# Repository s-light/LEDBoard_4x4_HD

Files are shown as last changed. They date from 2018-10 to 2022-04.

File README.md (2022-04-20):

<!--lint disable list-item-indent-->
<!--lint disable list-item-bullet-indent-->

# LEDBoard_4x4_HD
PCB originally designed for [magic_amulet](https://github.com/s-light/magic_amulet),  
but now used in [magic_crystal](https://github.com/s-light/magic_crystal)

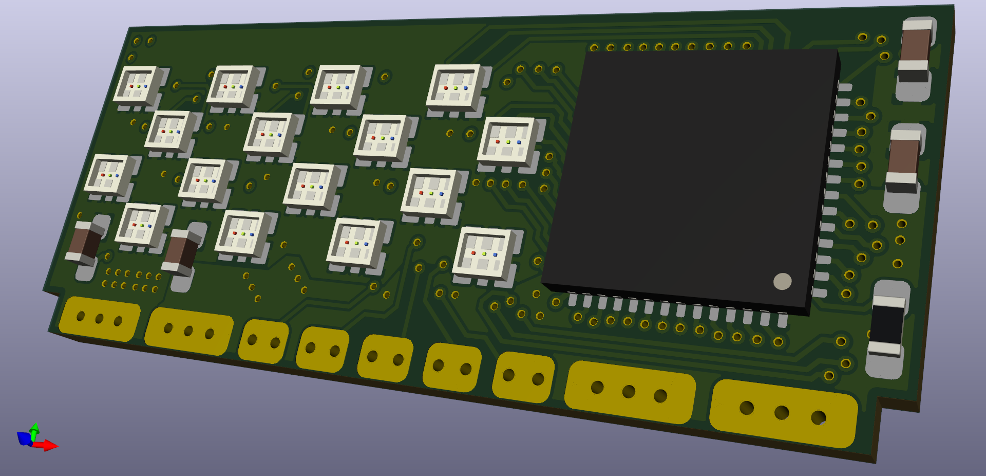
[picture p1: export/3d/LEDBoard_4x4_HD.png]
LEDBoard_4x4_HD CAD

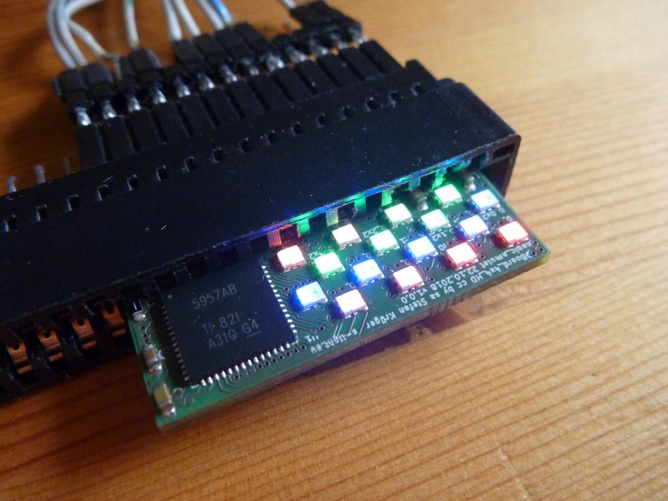
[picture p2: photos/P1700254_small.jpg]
LEDBoard_4x4_HD working

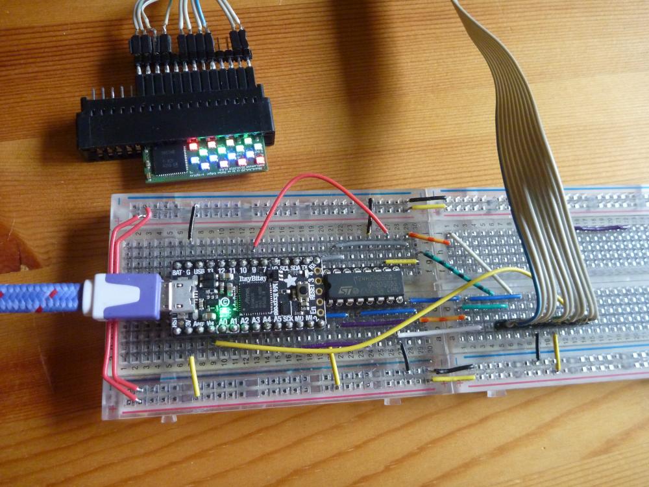
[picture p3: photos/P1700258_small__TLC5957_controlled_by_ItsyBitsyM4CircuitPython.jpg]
LEDBoard_4x4_HD controlled by ItsyBitsy M4 with CircuitPython


Overall Size:  
33mm x 14mm

### PCB
4layer board - uses 150mil traces and 100mil trace spacing  
shown pcb came from [aisler](https://aisler.net/s-light/magic_amulet/led-board-4x4-hd)

### parts
LED-Driver: [TLC5957](http://www.ti.com/lit/ds/symlink/tlc5957.pdf) (48ch CC 9-16Bit-PWM driver)  
more information in AppNote [Build a High-Density, High-Refresh Rate, Multiplexing Panel With the TLC5957](http://www.ti.com/lit/ug/slvuaf0/slvuaf0.pdf)

LED: [Rohm MSL0402RGBU](https://www.rohm.com/products/led/chip-leds-multi-color-type/msl0402rgbu-product) (1.8x1.6x0.5mm RGB)

### BOM
can be ordered with aisler parts-package  
or also with this [list at mouser](https://www.mouser.com/ProjectManager/ProjectDetail.aspx?AccessID=e53c13ed09)  
or with plain part numbers:
```
Qty.    Mfr. No             Manufacturer            Description
16      MSL0402RGBU1        ROHM Semiconductor      Standard LEDs - SMD RGB 624/527/470nm 5V 400/550/180mcd 30mA
1       TLC5957RTQR         Texas Instruments       LED Lighting Drivers 48-channel, 16bit ES PWM LED driver
2       GRM188R61A226ME15D  Murata                  Multilayer Ceramic Capacitors MLCC - SMD/SMT 0603 22uF 10volts *Derate Voltage/Temp
2       GCM188R91E104KA37D  Murata                  Multilayer Ceramic Capacitors MLCC - SMD/SMT 0603 0.1uF 25volts X8R 10%
1       ERJ-PB3B7501V       Panasonic               Thick Film Resistors - SMD 0603 Anti-Surge Res. 0.1%, 7.5Kohm
```

### power & cooling
if you want to drive the leds with full power (up to 25mA/color)
you definitely need a heatsink.  
the pcb backside get to >= 60°C very fast without a heatsink!

also remember that one board needs up to 1.2A@5V = 6W

### constant current

```
RIREF(kΩ) = VIREF(V) / IOLCMax(mA)× Gain  | / Gain
RIREF(kΩ) / Gain = VIREF(V) / IOLCMax(mA)  | swap
Gain / RIREF(kΩ) = IOLCMax(mA) / VIREF(V)  | x VIREF(V)
Gain / RIREF(kΩ) x VIREF(V) = IOLCMax(mA)

Gain / 7.4kΩ x 1.2V = IOLCMax(mA)

```
|  Gain |  BC | IOLCMax |
| ----: | --: | ---: |
|  20.0 | 0x0 | 3.2mA |
|  39.5 | 0x1 | 6.4mA |
|  58.6 | 0x2 | 9.5mA |
|  80.9 | 0x3 |  13.1mA |
| 100.0 | 0x4 |  16.2mA |
| 113.3 | 0x5 |  18.4mA |
| 141.6 | 0x6 |  23.0mA |
| 154.5 | 0x7 |  25.0mA |

### Software
- [arduino library](https://github.com/s-light/slight_TLC5957)
- [CircuitPython library](https://github.com/s-light/slight_CircuitPython_TLC5957)

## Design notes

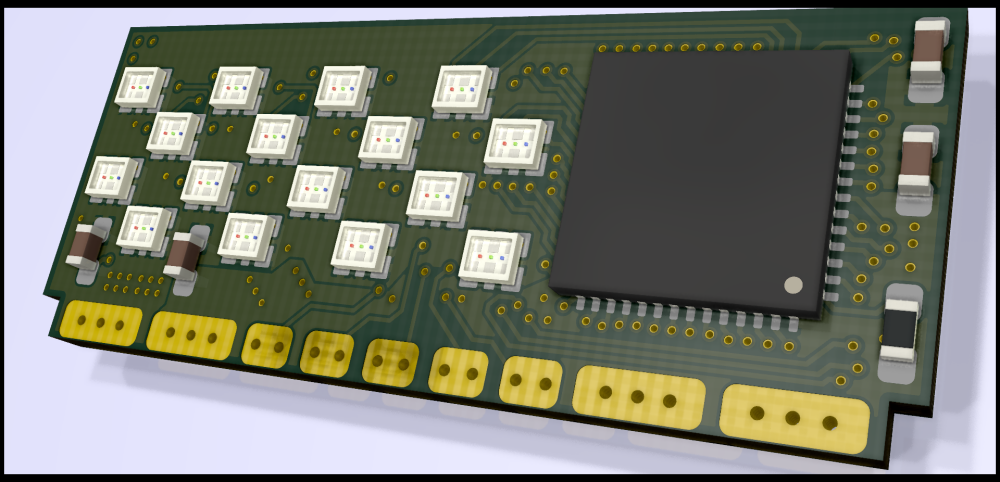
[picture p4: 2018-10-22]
export/3d/LEDBoard_4x4_HD_rendered_small.png

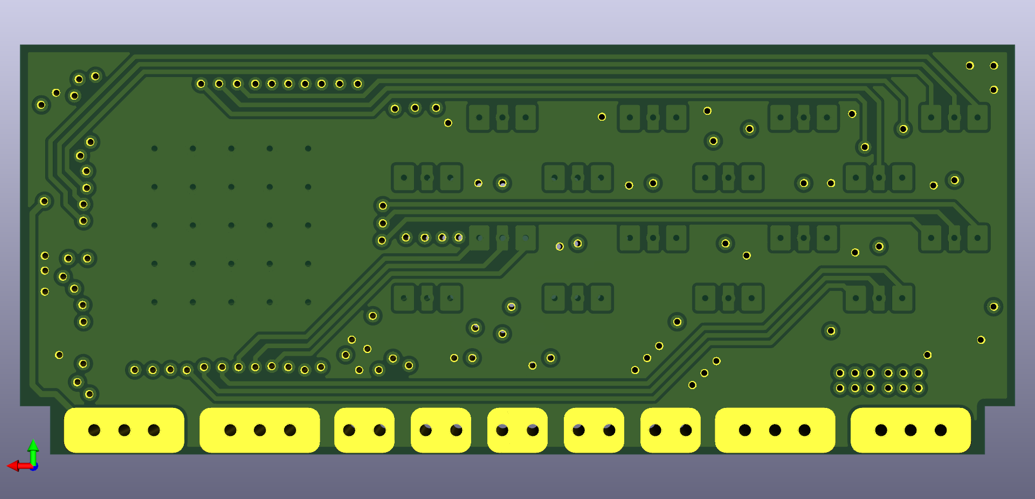
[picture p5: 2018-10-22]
export/3d/LEDBoard_4x4_HD_back.png

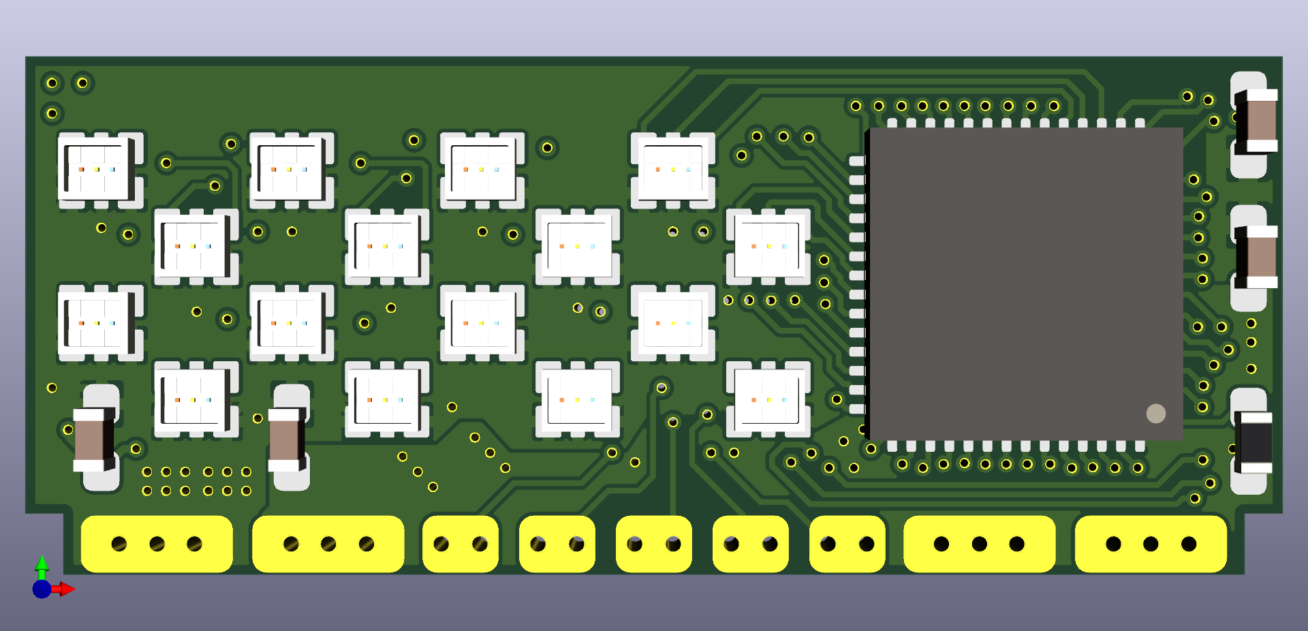
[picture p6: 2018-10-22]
export/3d/LEDBoard_4x4_HD_front.png

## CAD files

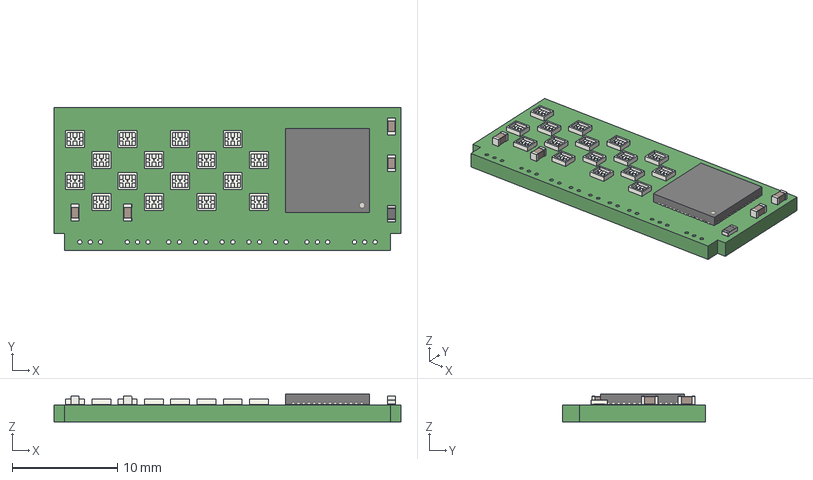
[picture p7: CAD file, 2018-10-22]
export/3d/LEDBoard_4x4_HD.step
33.0 x 13.6 x 2.65 mm

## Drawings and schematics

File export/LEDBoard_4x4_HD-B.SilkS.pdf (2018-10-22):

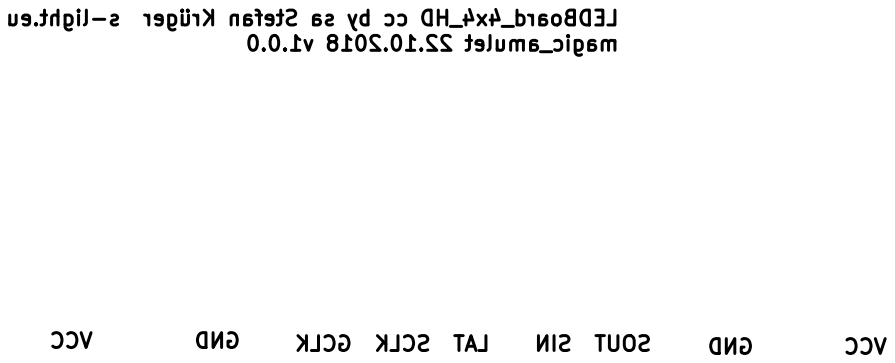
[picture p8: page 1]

LEDBoard_4x4_HD cc by sa Stefan Krüger s-light.eu magic_amulet 22.10.2018 v1.0.0

GND VCC SOUT SIN LAT SCLK GCLK VCC GND

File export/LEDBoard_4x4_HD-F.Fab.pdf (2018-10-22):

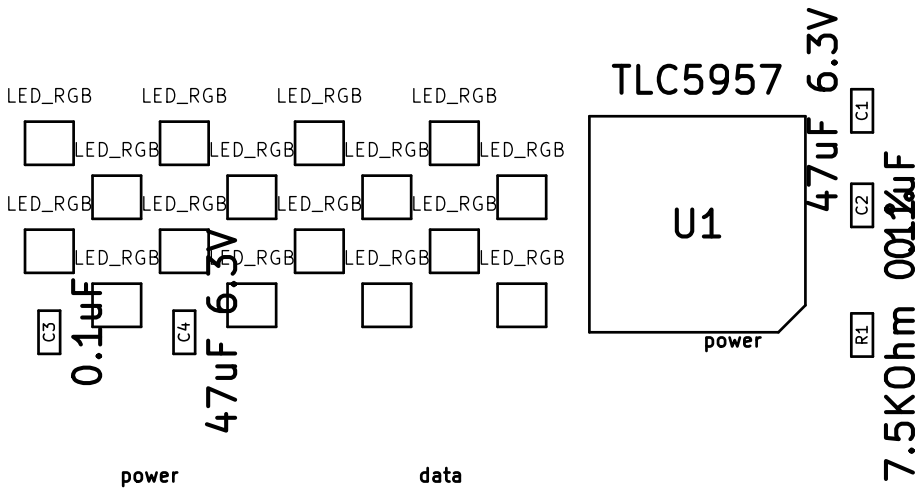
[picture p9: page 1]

LED_RGB | LED_RGB | LED_RGB

LED_RGB | | LED_RGB | LED_RGB

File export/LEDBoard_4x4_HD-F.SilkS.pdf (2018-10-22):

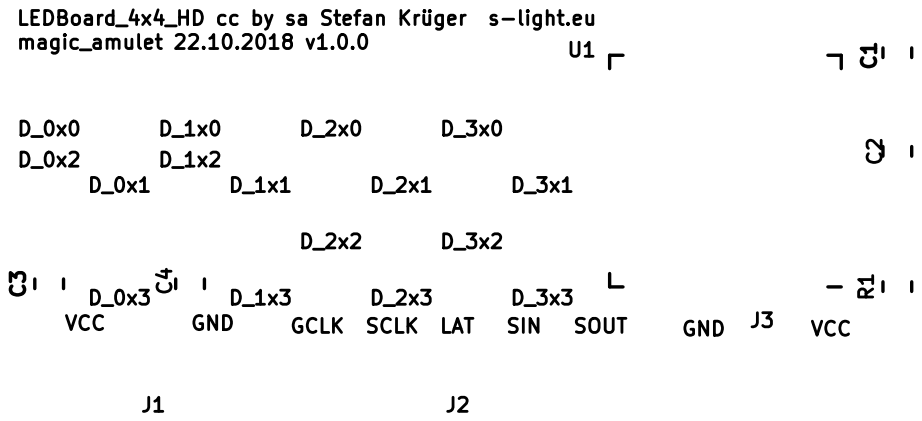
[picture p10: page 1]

LEDBoard_4x4_HD cc by sa Stefan Krüger s-light.eu magic_amulet 22.10.2018 v1.0.0

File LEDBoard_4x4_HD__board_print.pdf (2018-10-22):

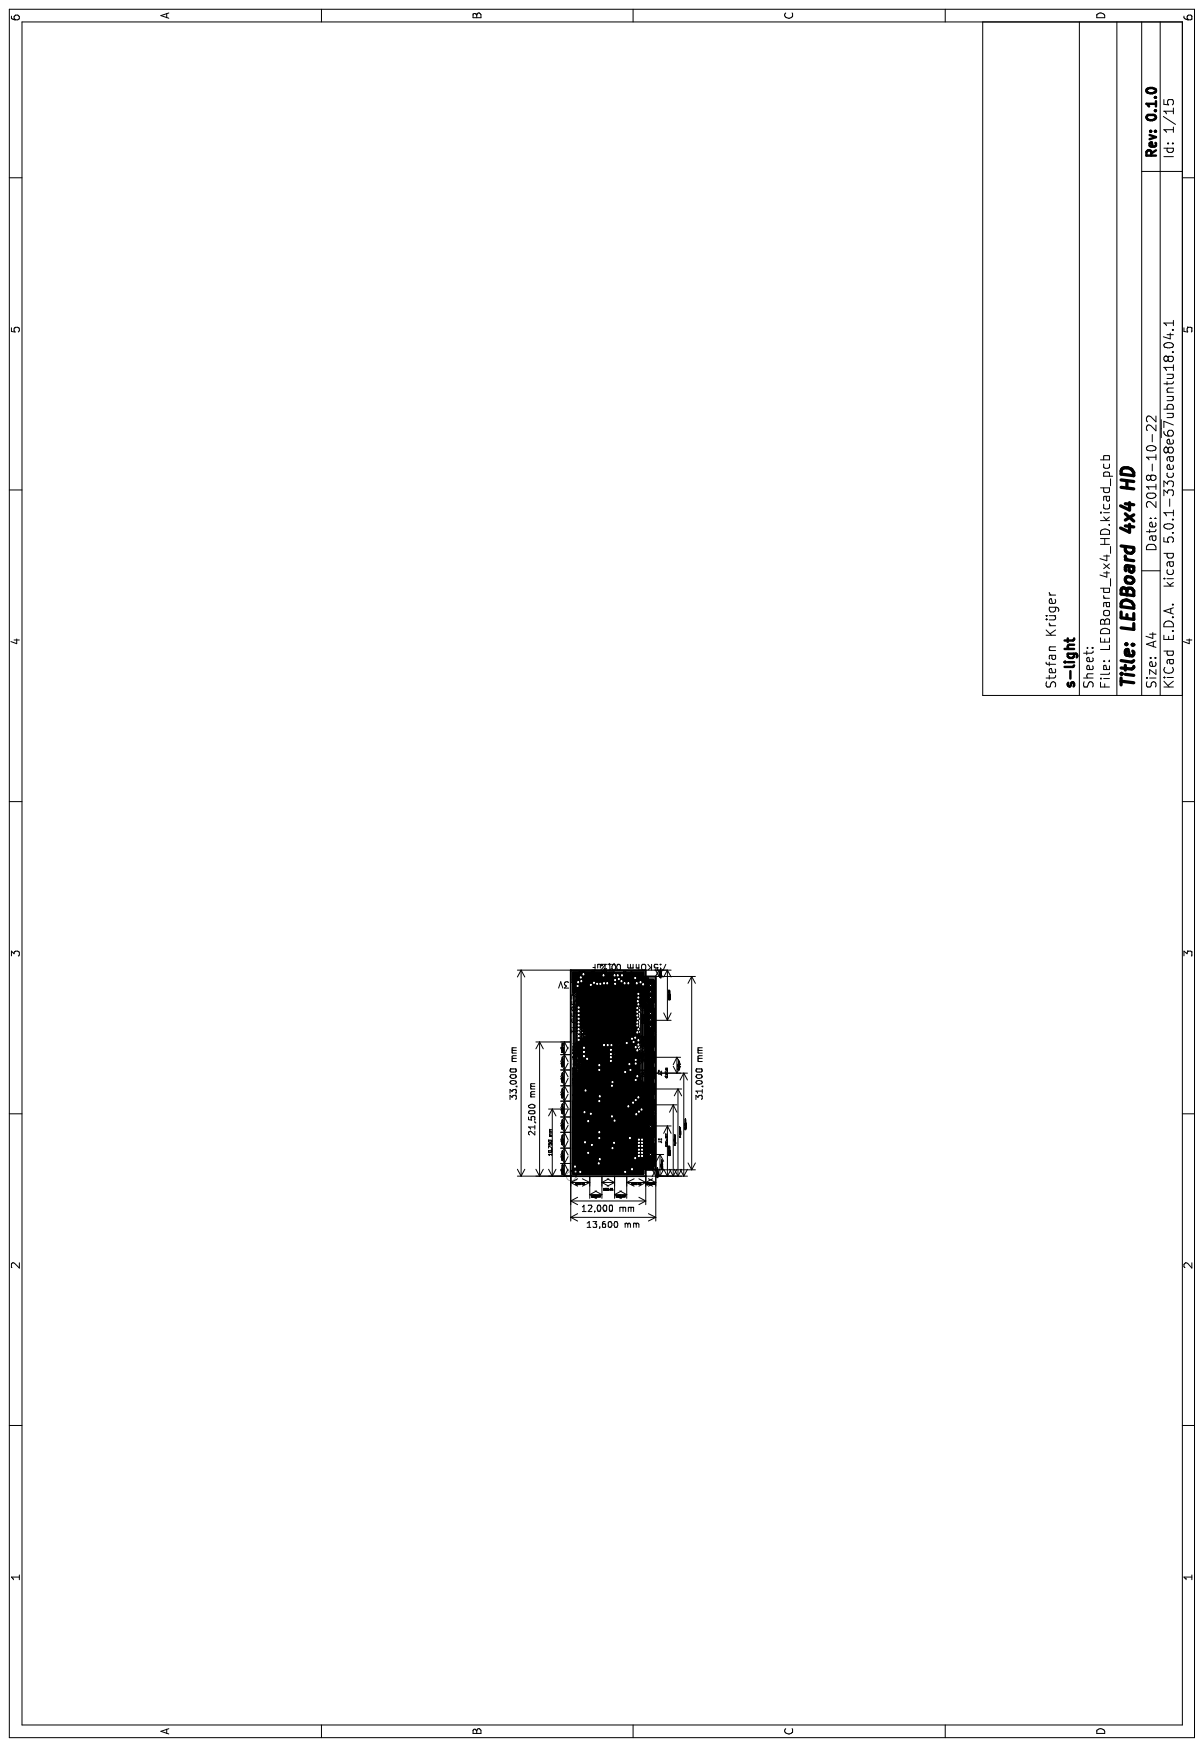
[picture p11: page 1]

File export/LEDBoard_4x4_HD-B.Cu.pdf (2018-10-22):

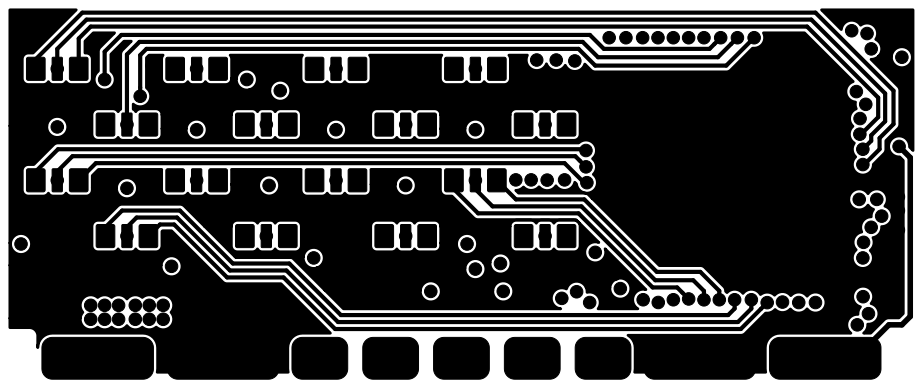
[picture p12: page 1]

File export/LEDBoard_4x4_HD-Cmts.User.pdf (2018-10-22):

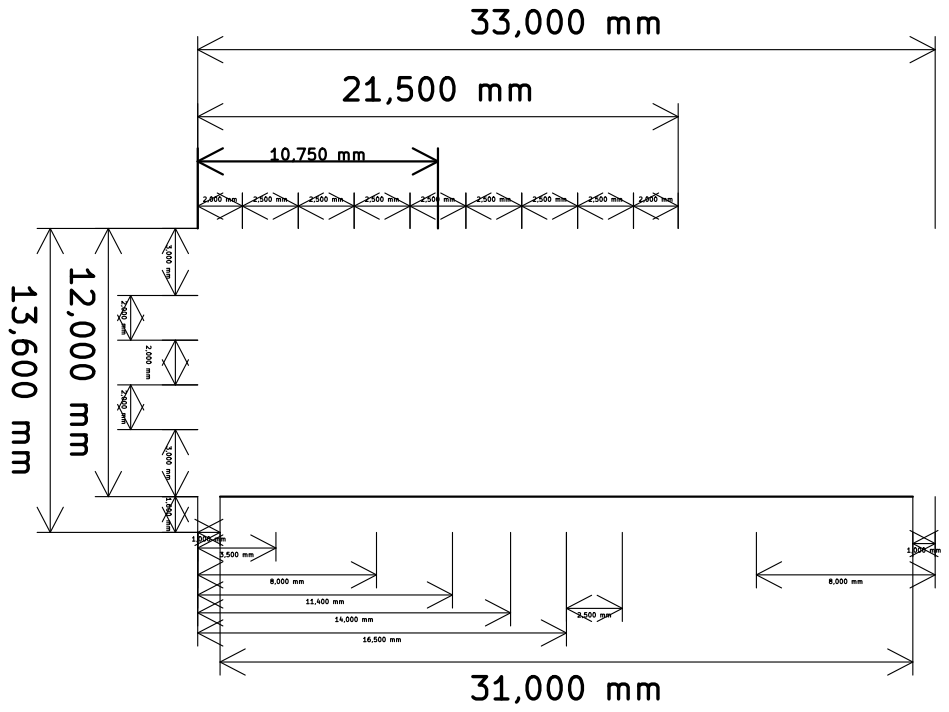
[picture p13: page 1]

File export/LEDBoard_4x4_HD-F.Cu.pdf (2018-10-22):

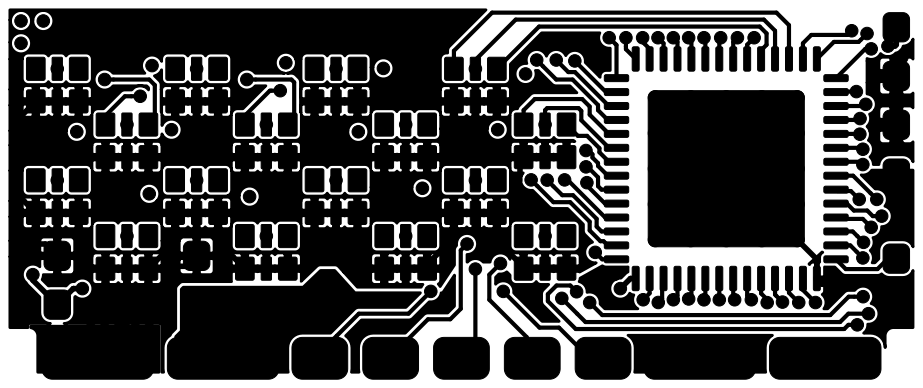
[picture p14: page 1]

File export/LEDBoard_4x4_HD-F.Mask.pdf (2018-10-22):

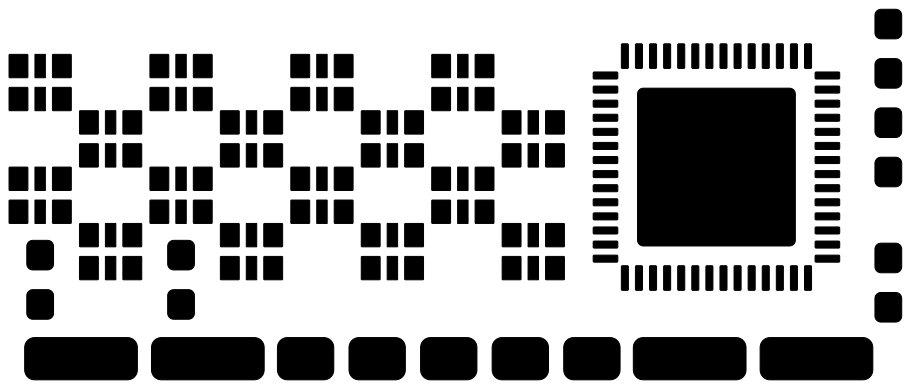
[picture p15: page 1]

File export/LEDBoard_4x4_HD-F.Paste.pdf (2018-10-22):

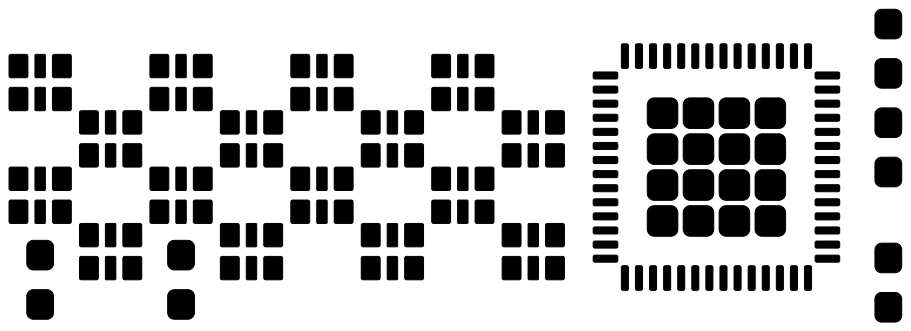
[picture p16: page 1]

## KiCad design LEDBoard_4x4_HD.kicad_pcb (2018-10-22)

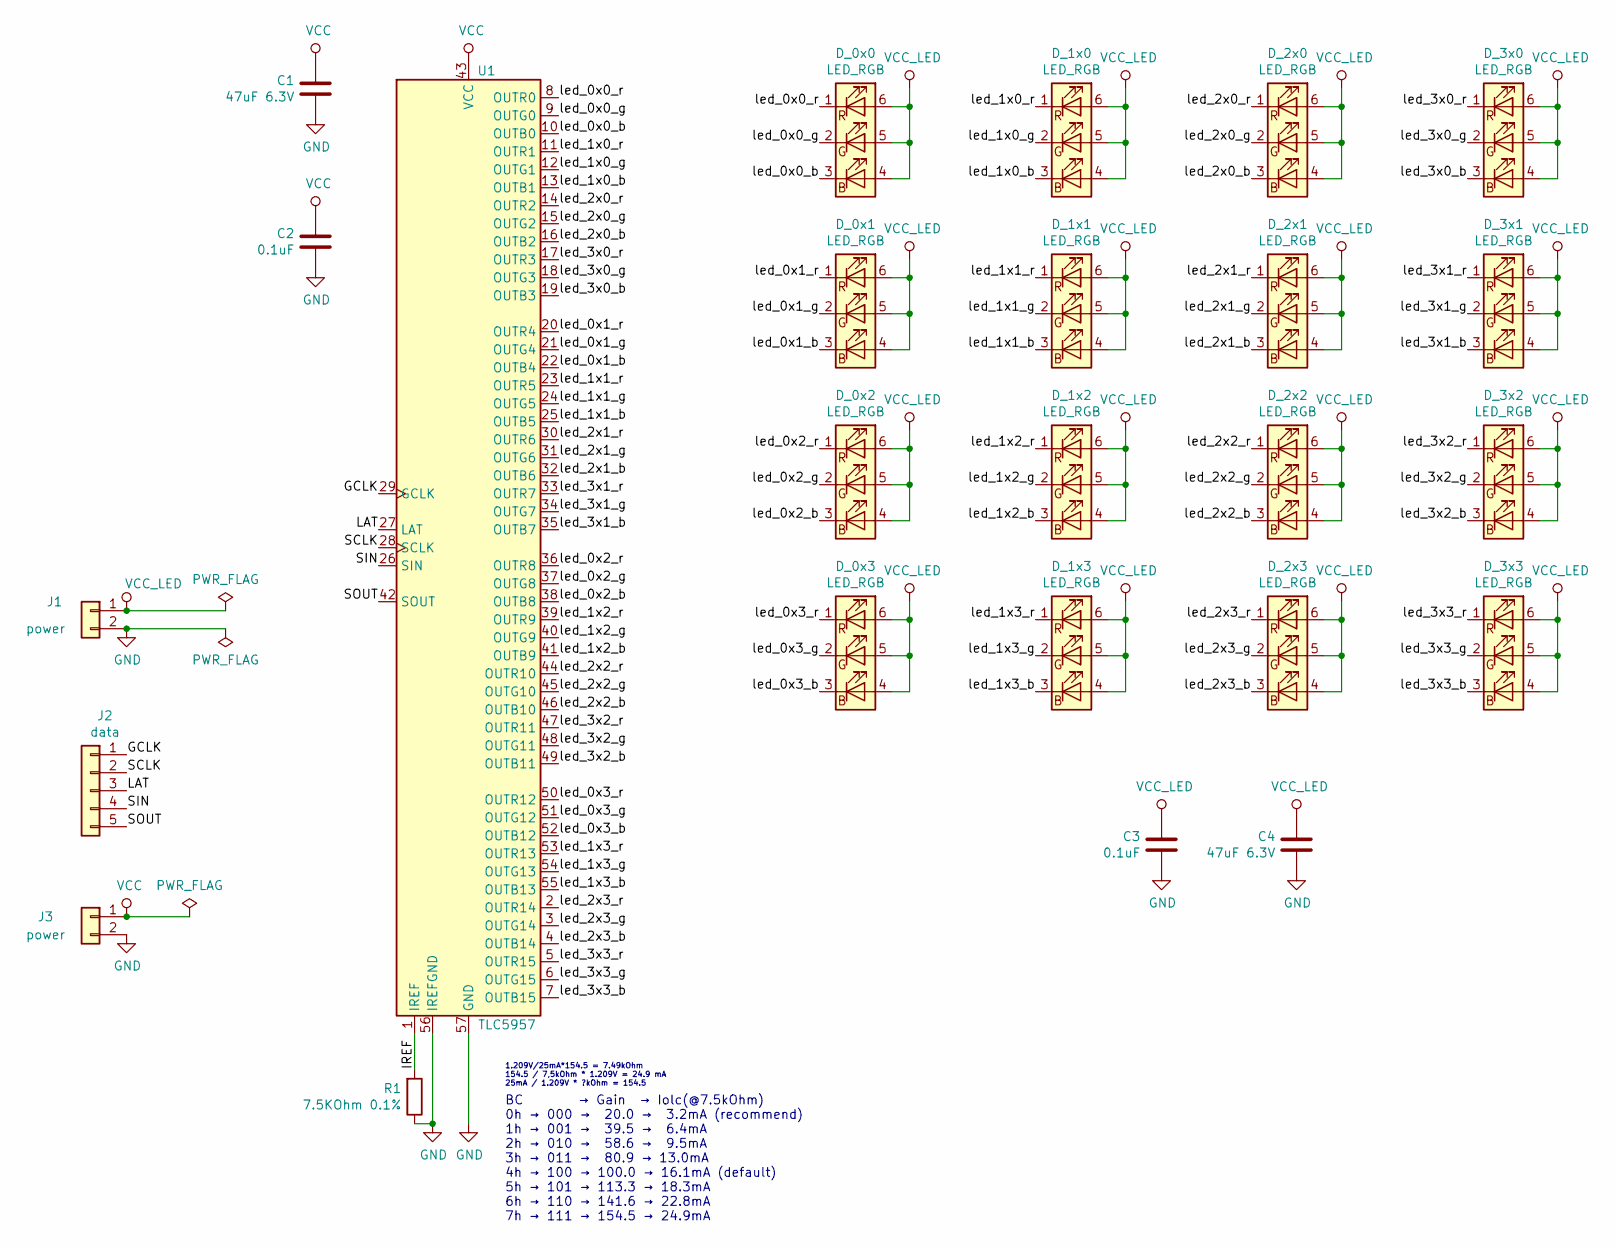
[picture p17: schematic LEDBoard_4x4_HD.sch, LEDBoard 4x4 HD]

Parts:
C1, C4: 47uF 6.3V; C_0603_1608Metric_Pad1.05x0.95mm_HandSolder
C2, C3: 0.1uF; C_0603_1608Metric_Pad1.05x0.95mm_HandSolder
D_0x0, D_0x1, D_0x2, D_0x3, D_1x0, D_1x1, D_1x2, D_1x3, D_2x0, D_2x1, D_2x2, D_2x3, D_3x0, D_3x1, D_3x2, D_3x3: LED_RGB; LED_RGB_0706_1816Metric_ROHM_ThermalVias
J1, J3: power; Conn_01x02_SMD_90deg_SolderMount
J2: data; Conn_01x05_SMD_90deg_SolderMount
R1: 7.5KOhm 0.1%; R_0603_1608Metric_Pad1.05x0.95mm_HandSolder
U1: TLC5957; QFN-56-1EP_8x8mm_P0.5mm_EP5.6x5.6mm_ThermalVias

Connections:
/GCLK: J2.1, U1.29 (GCLK)
/IREF: R1.2, U1.1 (IREF)
/LAT: J2.3, U1.27 (LAT)
/SCLK: J2.2, U1.28 (SCLK)
/SIN: J2.4, U1.26 (SIN)
/SOUT: J2.5, U1.42 (SOUT)
/led_0x0_b: D_0x0.3 (BK), U1.10 (OUTB0)
/led_0x0_g: D_0x0.2 (GK), U1.9 (OUTG0)
/led_0x0_r: D_0x0.1 (RK), U1.8 (OUTR0)
/led_0x1_b: D_0x1.3 (BK), U1.22 (OUTB4)
/led_0x1_g: D_0x1.2 (GK), U1.21 (OUTG4)
/led_0x1_r: D_0x1.1 (RK), U1.20 (OUTR4)
/led_0x2_b: D_0x2.3 (BK), U1.38 (OUTB8)
/led_0x2_g: D_0x2.2 (GK), U1.37 (OUTG8)
/led_0x2_r: D_0x2.1 (RK), U1.36 (OUTR8)
/led_0x3_b: D_0x3.3 (BK), U1.52 (OUTB12)
/led_0x3_g: D_0x3.2 (GK), U1.51 (OUTG12)
/led_0x3_r: D_0x3.1 (RK), U1.50 (OUTR12)
/led_1x0_b: D_1x0.3 (BK), U1.13 (OUTB1)
/led_1x0_g: D_1x0.2 (GK), U1.12 (OUTG1)
/led_1x0_r: D_1x0.1 (RK), U1.11 (OUTR1)
/led_1x1_b: D_1x1.3 (BK), U1.25 (OUTB5)
/led_1x1_g: D_1x1.2 (GK), U1.24 (OUTG5)
/led_1x1_r: D_1x1.1 (RK), U1.23 (OUTR5)
/led_1x2_b: D_1x2.3 (BK), U1.41 (OUTB9)
/led_1x2_g: D_1x2.2 (GK), U1.40 (OUTG9)
/led_1x2_r: D_1x2.1 (RK), U1.39 (OUTR9)
/led_1x3_b: D_1x3.3 (BK), U1.55 (OUTB13)
/led_1x3_g: D_1x3.2 (GK), U1.54 (OUTG13)
/led_1x3_r: D_1x3.1 (RK), U1.53 (OUTR13)
/led_2x0_b: D_2x0.3 (BK), U1.16 (OUTB2)
/led_2x0_g: D_2x0.2 (GK), U1.15 (OUTG2)
/led_2x0_r: D_2x0.1 (RK), U1.14 (OUTR2)
/led_2x1_b: D_2x1.3 (BK), U1.32 (OUTB6)
/led_2x1_g: D_2x1.2 (GK), U1.31 (OUTG6)
/led_2x1_r: D_2x1.1 (RK), U1.30 (OUTR6)
/led_2x2_b: D_2x2.3 (BK), U1.46 (OUTB10)
/led_2x2_g: D_2x2.2 (GK), U1.45 (OUTG10)
/led_2x2_r: D_2x2.1 (RK), U1.44 (OUTR10)
/led_2x3_b: D_2x3.3 (BK), U1.4 (OUTB14)
/led_2x3_g: D_2x3.2 (GK), U1.3 (OUTG14)
/led_2x3_r: D_2x3.1 (RK), U1.2 (OUTR14)
/led_3x0_b: D_3x0.3 (BK), U1.19 (OUTB3)
/led_3x0_g: D_3x0.2 (GK), U1.18 (OUTG3)
/led_3x0_r: D_3x0.1 (RK), U1.17 (OUTR3)
/led_3x1_b: D_3x1.3 (BK), U1.35 (OUTB7)
/led_3x1_g: D_3x1.2 (GK), U1.34 (OUTG7)
/led_3x1_r: D_3x1.1 (RK), U1.33 (OUTR7)
/led_3x2_b: D_3x2.3 (BK), U1.49 (OUTB11)
/led_3x2_g: D_3x2.2 (GK), U1.48 (OUTG11)
/led_3x2_r: D_3x2.1 (RK), U1.47 (OUTR11)
/led_3x3_b: D_3x3.3 (BK), U1.7 (OUTB15)
/led_3x3_g: D_3x3.2 (GK), U1.6 (OUTG15)
/led_3x3_r: D_3x3.1 (RK), U1.5 (OUTR15)
GND: C1.1, C2.1, C3.1, C4.1, J1.2, J3.2, R1.1, U1.56 (IREFGND), U1.57 (GND)
VCC: C1.2, C2.2, J3.1, U1.43 (VCC)
VCC_LED: C3.2, C4.2, D_0x0.4 (BA), D_0x0.5 (GA), D_0x0.6 (RA), D_0x1.4 (BA), D_0x1.5 (GA), D_0x1.6 (RA), D_0x2.4 (BA), D_0x2.5 (GA), D_0x2.6 (RA), D_0x3.4 (BA), D_0x3.5 (GA), D_0x3.6 (RA), D_1x0.4 (BA), D_1x0.5 (GA), D_1x0.6 (RA), D_1x1.4 (BA), D_1x1.5 (GA), D_1x1.6 (RA), D_1x2.4 (BA), D_1x2.5 (GA), D_1x2.6 (RA), D_1x3.4 (BA), D_1x3.5 (GA), D_1x3.6 (RA), D_2x0.4 (BA), D_2x0.5 (GA), D_2x0.6 (RA), D_2x1.4 (BA), D_2x1.5 (GA), D_2x1.6 (RA), D_2x2.4 (BA), D_2x2.5 (GA), D_2x2.6 (RA), D_2x3.4 (BA), D_2x3.5 (GA), D_2x3.6 (RA), D_3x0.4 (BA), D_3x0.5 (GA), D_3x0.6 (RA), D_3x1.4 (BA), D_3x1.5 (GA), D_3x1.6 (RA), D_3x2.4 (BA), D_3x2.5 (GA), D_3x2.6 (RA), D_3x3.4 (BA), D_3x3.5 (GA), D_3x3.6 (RA), J1.1

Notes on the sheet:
BC → Gain → Iolc(@7.5kOhm) 0h → 000 → 20.0 → 3.2mA (recommend) 1h → 001 → 39.5 → 6.4mA 2h → 010 → 58.6 → 9.5mA 3h → 011 → 80.9 → 13.0mA 4h → 100 → 100.0 → 16.1mA (default) 5h → 101 → 113.3 → 18.3mA 6h → 110 → 141.6 → 22.8mA 7h → 111 → 154.5 → 24.9mA
1.209V/25mA*154.5 = 7.49kOhm 154.5 / 7,5kOhm * 1.209V = 24.9 mA 25mA / 1.209V * ?kOhm = 154.5

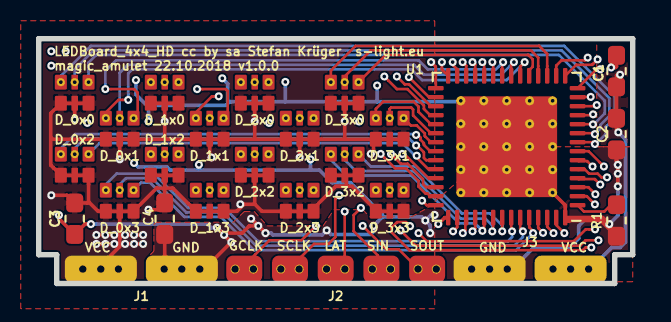
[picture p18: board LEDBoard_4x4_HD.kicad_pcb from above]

Board: 4 copper layers, 33.0 x 13.6 mm, 25 parts (0 on the bottom side), 57 nets.

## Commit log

2018-10-16 added LEDBoard_4x4_HD
    [LEDBoard_4x4_HD.kicad_pcb, LEDBoard_4x4_HD.sch]
2018-10-19 LEDBoard parts positioned & routing started
    [LEDBoard_4x4_HD.kicad_pcb, LEDBoard_4x4_HD.sch]
2018-10-20 first routing done
    [LEDBoard_4x4_HD.kicad_pcb, LEDBoard_4x4_HD.sch]
2018-10-20 first layout finished
    [LEDBoard_4x4_HD.kicad_pcb, LEDBoard_4x4_HD.sch]
2018-10-20 added dimensions & exported step
    [LEDBoard_4x4_HD.kicad_pcb, LEDBoard_4x4_HD.step]
2018-10-21 updated pcb fixed some small things added capacitor
    [LEDBoard_4x4_HD.kicad_pcb, LEDBoard_4x4_HD.sch]
2018-10-22 more layout tweeks + separate VCC for controler
    [LEDBoard_4x4_HD.kicad_pcb, LEDBoard_4x4_HD.sch]
2018-10-22 some more clean up and exporting
    [LEDBoard_4x4_HD.kicad_pcb, LEDBoard_4x4_HD.step]
2018-10-22 fixed silk print
    [LEDBoard_4x4_HD.kicad_pcb, LEDBoard_4x4_HD.sch]
2018-10-22 fixed zone connection for pad
    [LEDBoard_4x4_HD.kicad_pcb]
2018-10-22 fixed position of connector labels
    [LEDBoard_4x4_HD.kicad_pcb]
2018-10-22 added LED-models
    [LEDBoard_4x4_HD.kicad_pcb, LEDBoard_4x4_HD.step]
2018-10-26 :memo: added Links to LEDDriver
2019-03-09 rearranged folder structure
    [LEDBoard_4x4_HD.kicad_pcb, LEDBoard_4x4_HD.sch, LEDBoard_4x4_HD.step]
2019-03-20 add power info
2019-03-24 updated component
    [LEDBoard_4x4_HD.sch]
